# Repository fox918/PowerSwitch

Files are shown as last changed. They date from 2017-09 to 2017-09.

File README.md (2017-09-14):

# SmartPowerSwitch Project

## Idea
Having a simple and extensible way to switch 12V power with up to 10A with a microcontroller.
The intended use for the device is to remotely switch things at amateur radio repeater sites. 

## Concept
The idea is to use a Infineon SmartFET as powerswitch.
This reduces complexity because a lot of things are already taken care of and we can
further use the diagnostic outputs to measure the current.

Using an i2c GPIO expander and an i2c ADC allows for measuring supply voltage, current delivered to the output and temperature of the heatsink.

With a dip switch, we can change the address of both i2c devices simultaneously, therefore allowing 4 devices on the same i2c bus.

Look at [PowerSwitch Idea](./PowerSwitch_Idea.pdf) for a Block Schema.

## Current State
An initial approach of the [Schema](./Circuit_Schema_v2.pdf) and the PCB is done, after review a prototype shall be built.

### Current PCB
- [PCB Front](./PCB_front_v2.png) 
- [PCB_Back](./PCB_back_v2.png) 

### Current Issues
- Almost no protection circuits on the internal voltage source
- Current paths on the pcb not optimal (especially ground path)
- Choose a suitable connector for the i2c backplane (suggestion: rj12, JST SH or some 2.54mm connector)

## Further development
- Design a board to mount the two colored button
- Choose a ethernet enabled microcontroller and design a i2c shield for it 
(and a nice GUI)
- adapt the boards to mount into 1U rackunits with XLR 4-Pin connectors

## License
[MIT, 2017 Oliver Wisler](./LICENSE)

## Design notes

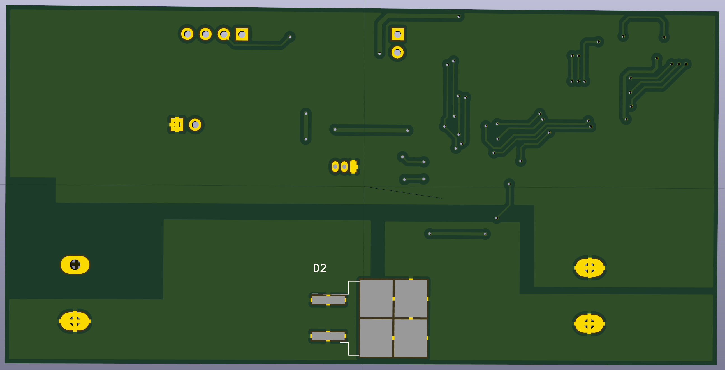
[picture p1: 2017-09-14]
PCB_back_v2.png

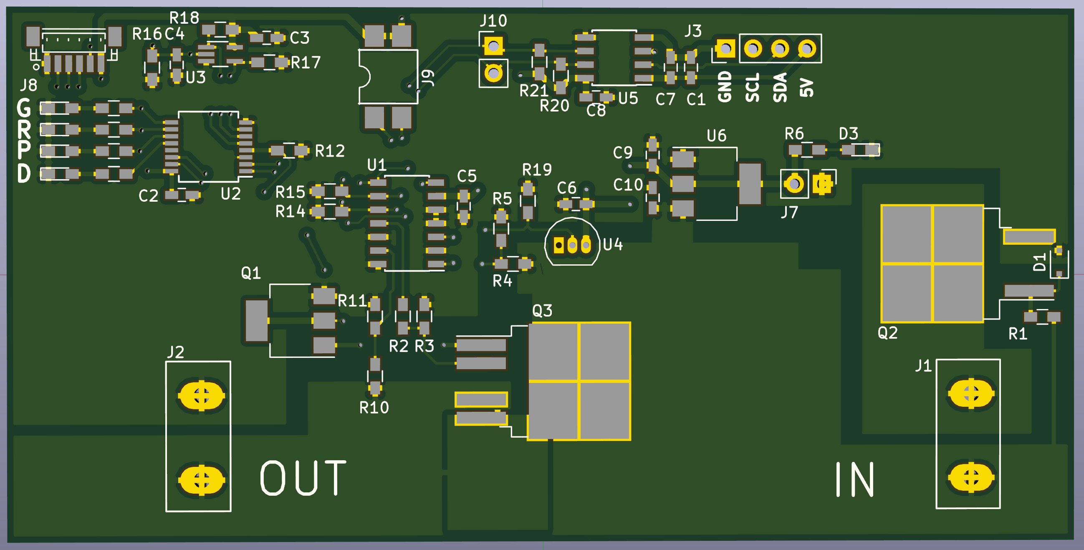
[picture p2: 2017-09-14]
PCB_front_v2.png

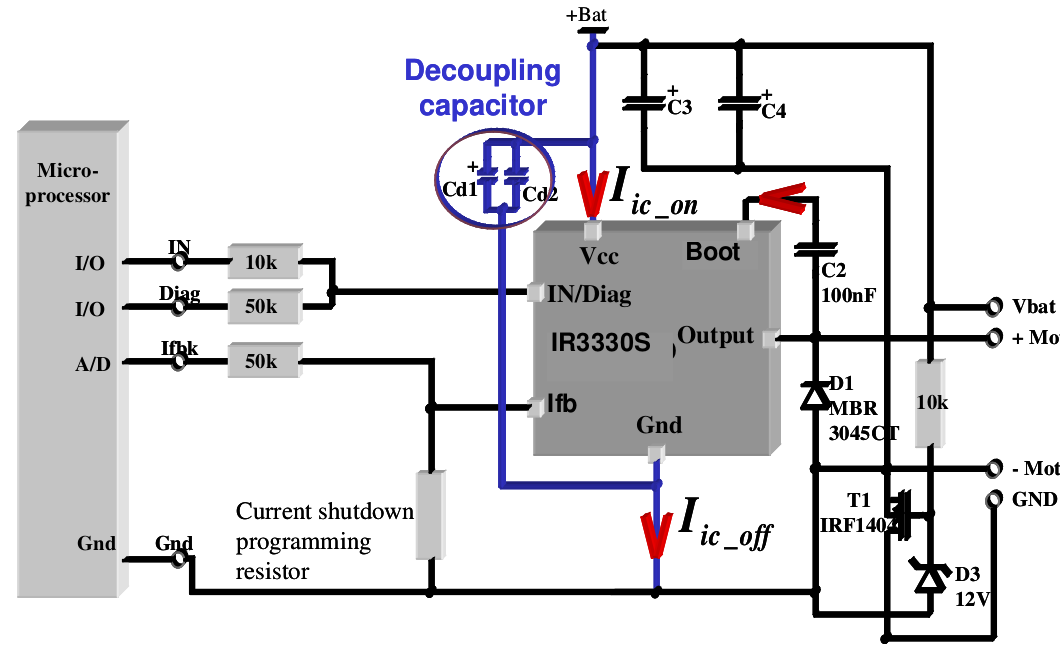
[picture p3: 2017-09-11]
Datasheets/Sample_Circuit_from_AUIR3330S.png

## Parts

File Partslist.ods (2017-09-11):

PowerSwitch Project Partslist
 |  | Green marked: | Parts chosen for the project
 |  | not marked | proposals, parts to keep an eye on
Connectors
Amount | Order Number | Part Nr | Description | Package
2 | 534-979 | 1327G6 | Powerpole Black
2 | 534-985 | 1327 | Powerpole Red
4 | 382-6108 | 1377G2 | Powerpole Right Angle PCB
 |  |  | RJ12 for i2c Connection to uC?
Button Circuit
Amount | Order Number | Part Nr | Description | Package
 |  | HB215SKG03CF-JB | NKK Taster R/G
 |  | FL12DRG5 | EOZ Taster R/G, too big?
1 | 198-069 | JB-15KNP2-KBS | NKK Taster Blau
1 | 816-8794 | 74LVC1G80GW | Flip Flop Taster
Power / Voltage
Amount | Order Number | Part Nr | Description | Package
 | 906-4432 | BTS50055-1TMC | POWERFET, Sense, 17 A | PG-TO220-7-4
 | 784-9338 | AUIR3330S | HIGH Side Switch | D2Pak 7 Leads
1 | 725-9209 | AUIPS7111S | PowerFET IPS7 | D2Pak 5 Leads
 | Accessories
1 | 698-8117 | FK 244 13 D PAK | Kühlkörper Dpak
1 | 698-8111 | FK 244 13 D2 PAK | Kühlkörper D2Pak
1 | 753-2816 | BSP318S | Logic NFET | SOT-223
Reverse Current and Protection
Amount | Order Number | Part Nr | Description | Package
1 | 651-8759 | IRF1404ZSPBF | Crowbar | D2Pak 2 Leads
1 | 770-4863 | DDZ12CSF-7 | Diode for Crowbar 12V | SOD-323F
1 | .249-167 | STPS40L45CG | Free Wheel Schottky | D2Pak 2 Leads
1 | 738-2829 | 0326015.MXP | Sicherung 15 A ()
2 | 703-2792 | 8040.0003 | Sicherungshalter
Sensing / Diagnostics
Amount | Order Number | Part Nr | Description | Package
1 | 703-7945 | MCP3428-E/SL | 4 Kanal I2C ADC from Microchip | SOIC-14
1 | 815-0683 | PCA9554DB | LED Driver / GPIO Switch | SSOP 16
1 | 811-5595 |  | LM35 Temp Sens | TO-92

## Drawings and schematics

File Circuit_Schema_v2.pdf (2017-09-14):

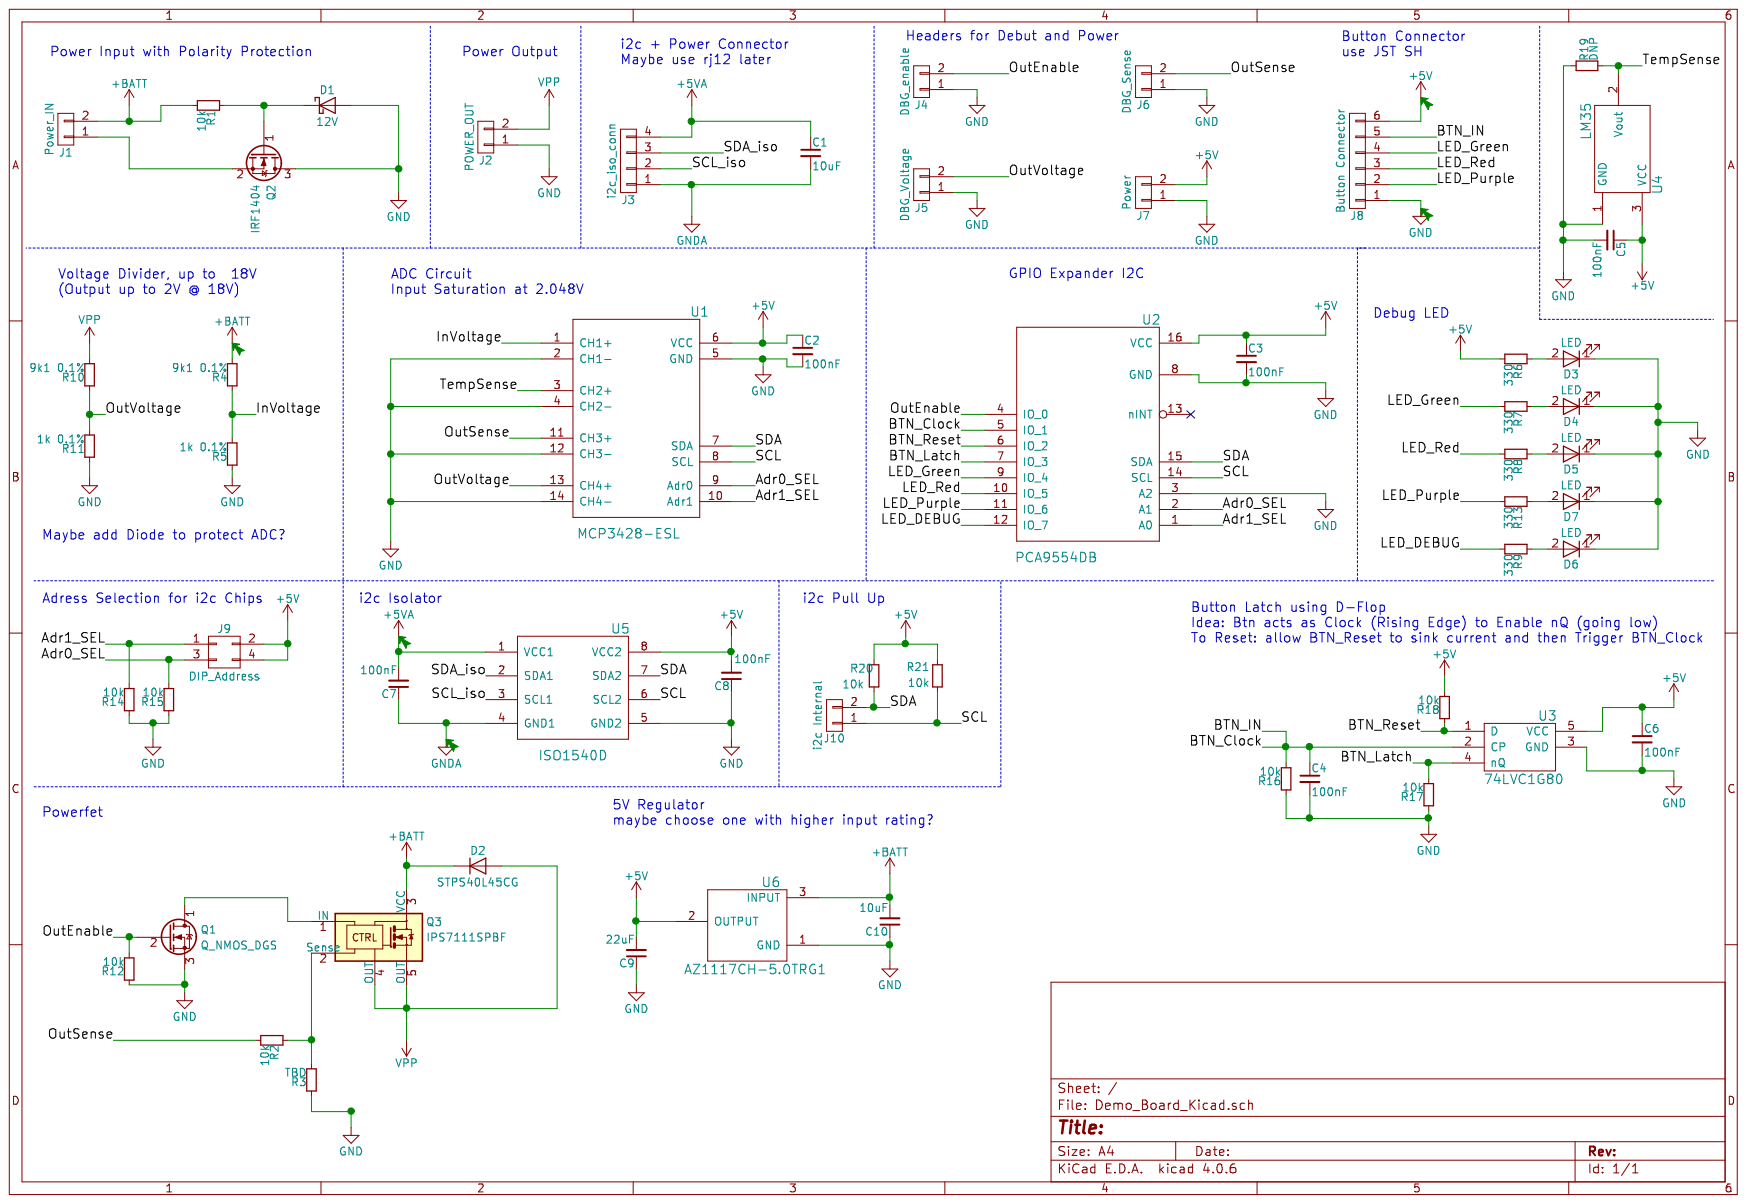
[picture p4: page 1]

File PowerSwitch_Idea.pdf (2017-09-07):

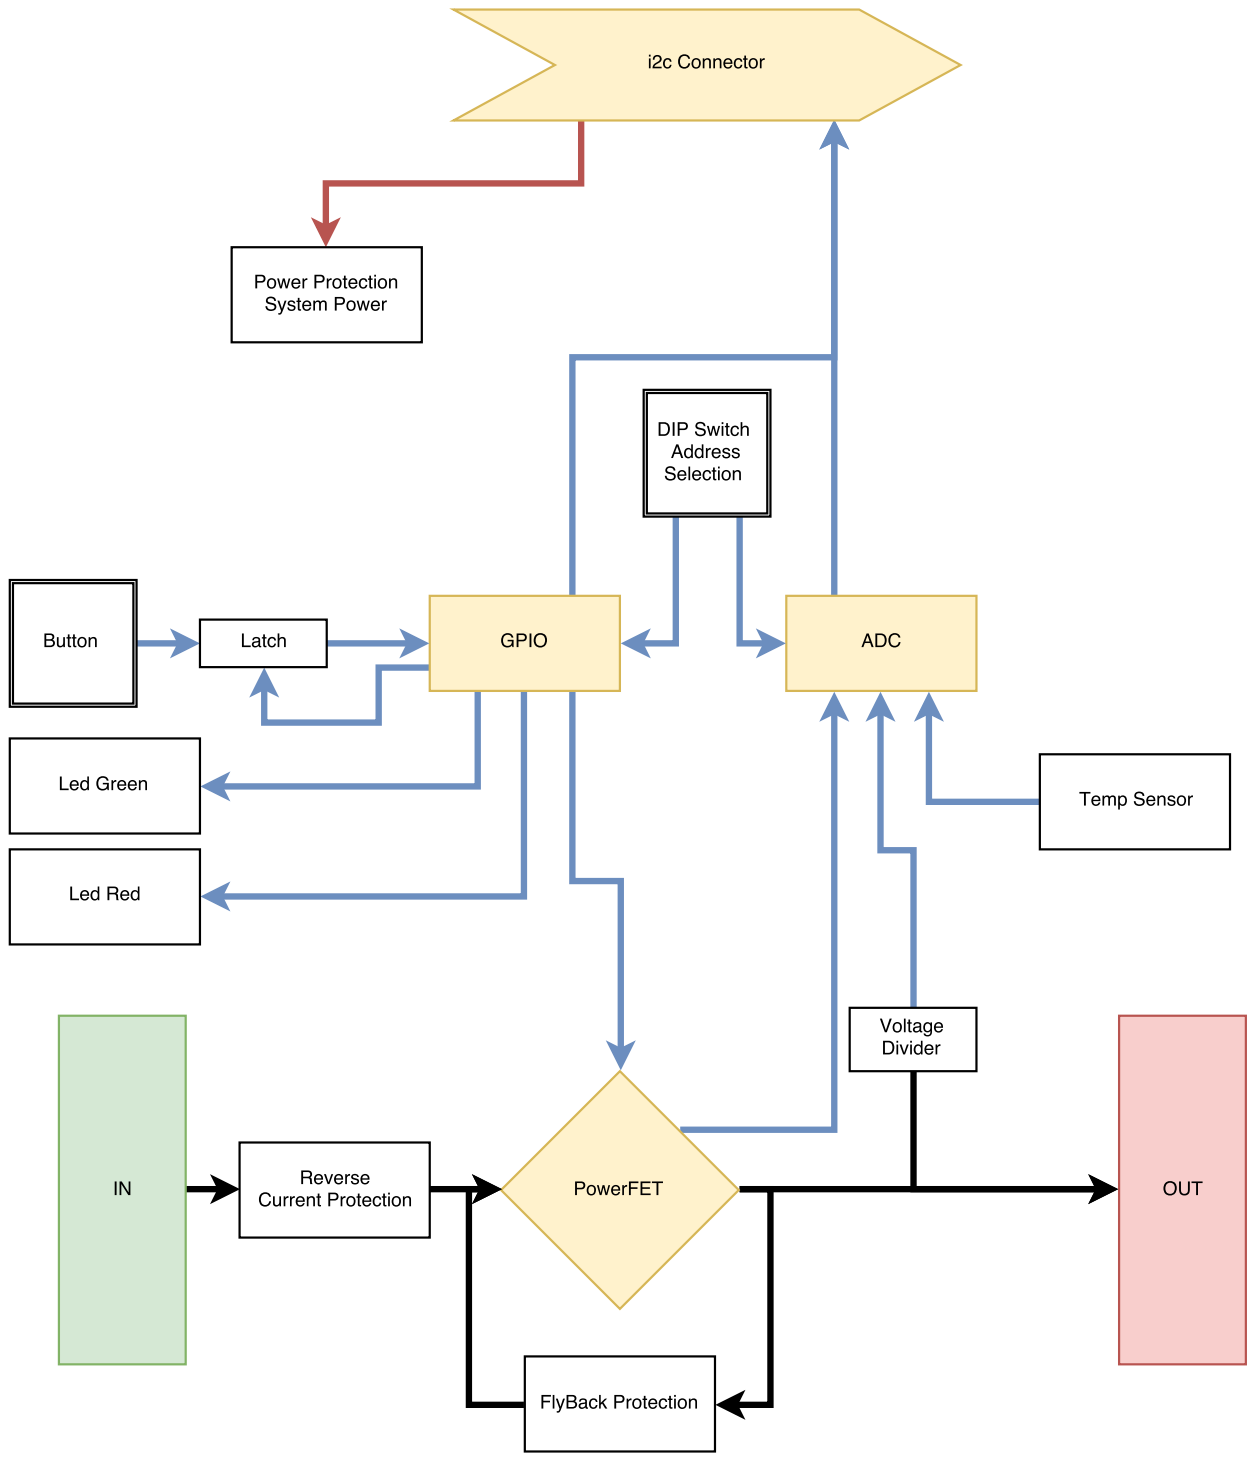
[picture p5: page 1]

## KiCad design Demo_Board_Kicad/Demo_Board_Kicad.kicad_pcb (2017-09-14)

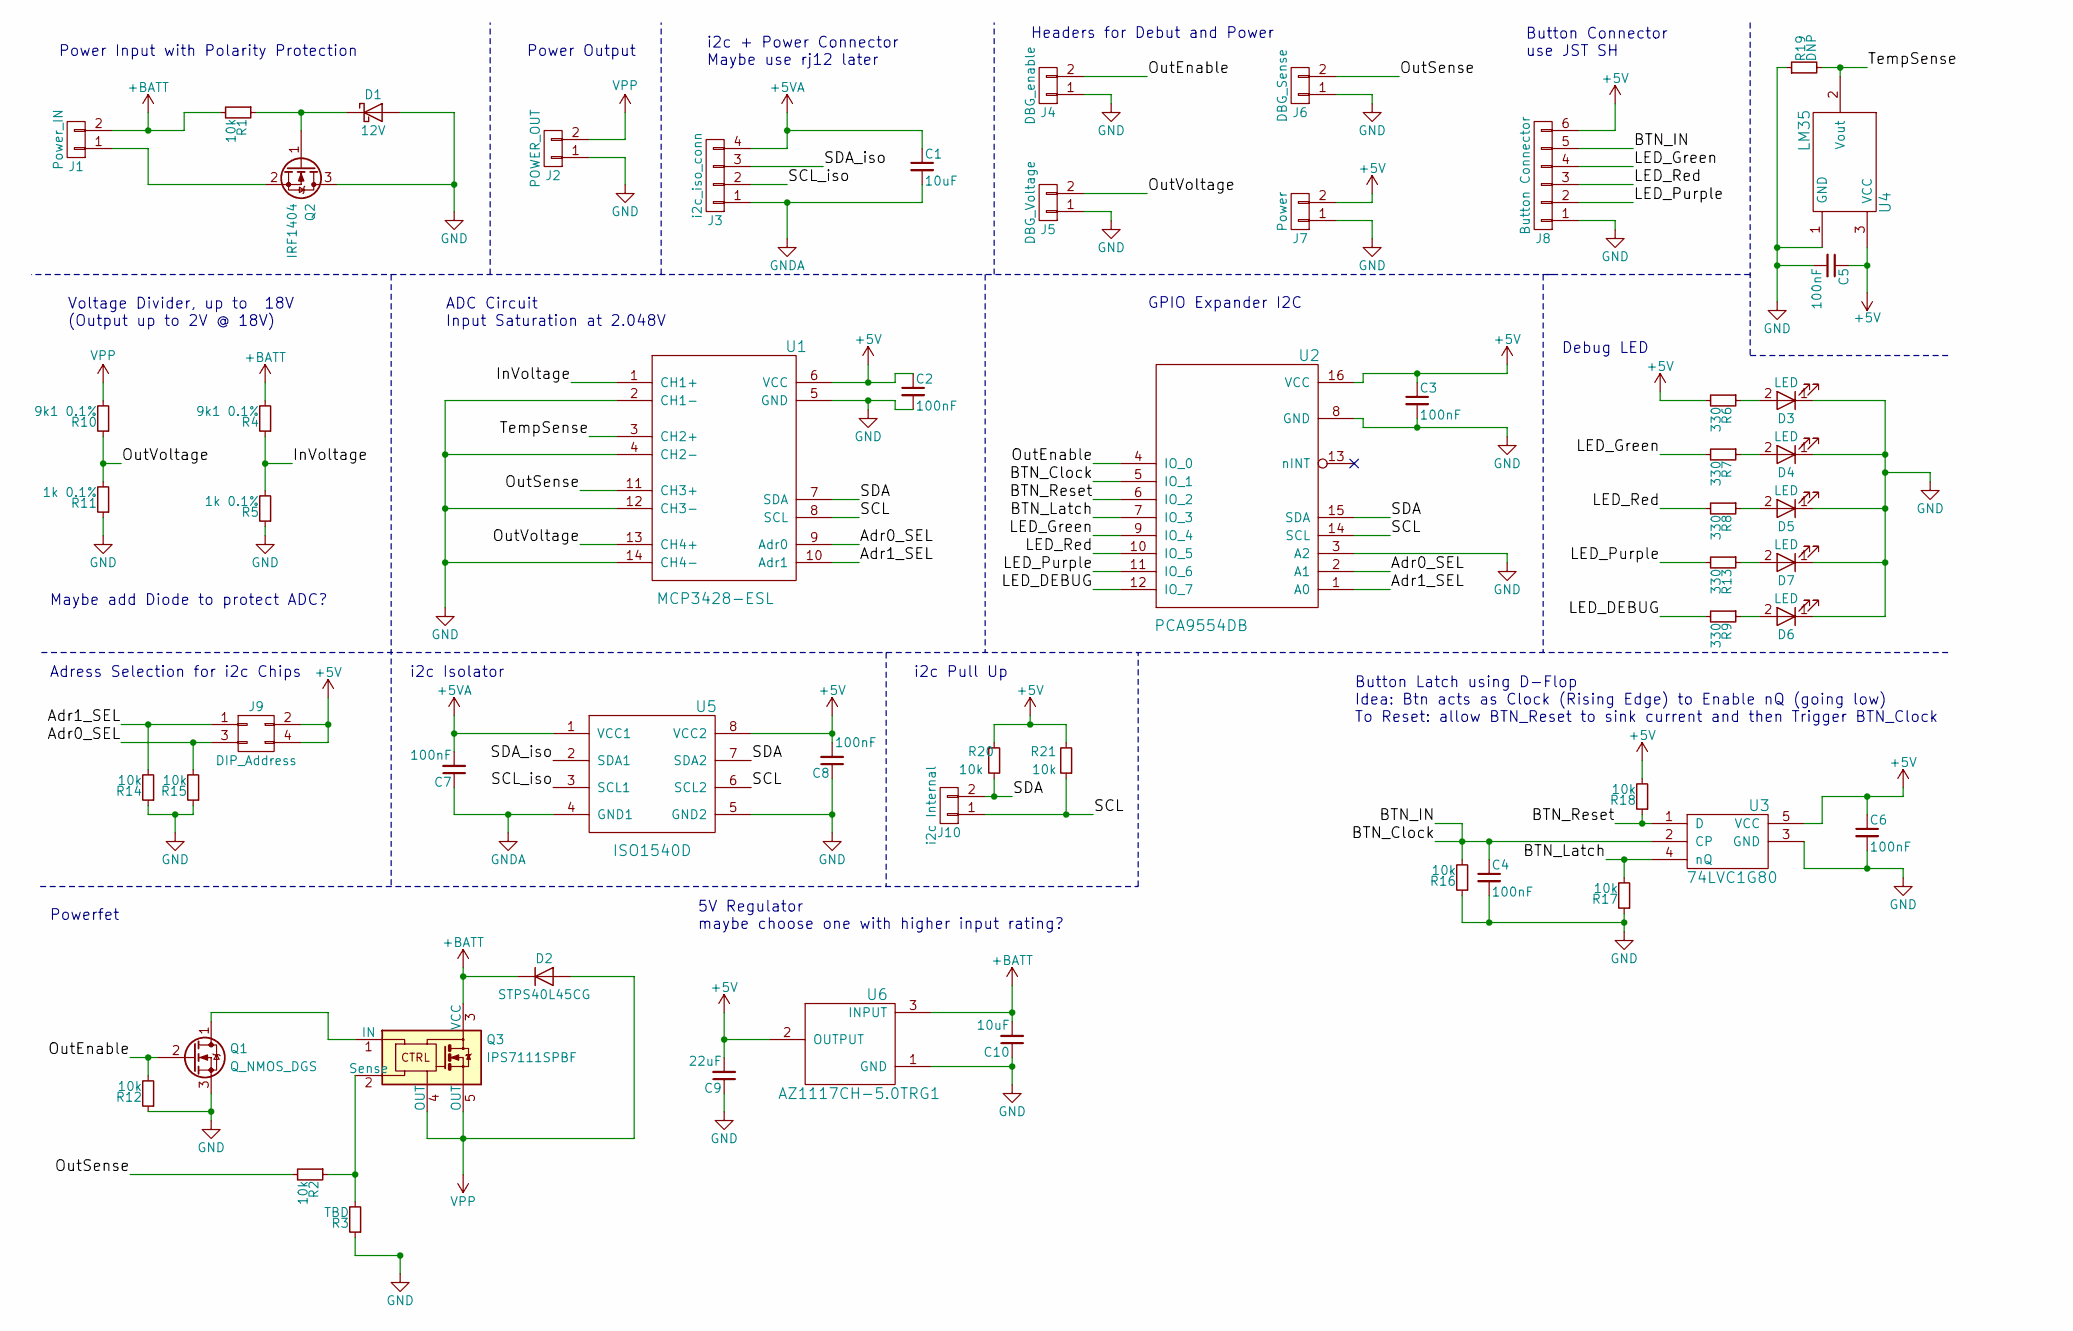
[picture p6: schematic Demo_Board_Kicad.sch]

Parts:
C1, C10: 10uF; C_0603_HandSoldering
C2, C3, C4, C5, C6, C7, C8: 100nF; C_0603_HandSoldering
C9: 22uF; C_0603_HandSoldering
D1: 12V; D_SOD-323F
D2: STPS40L45CG; TO-263-2
D3, D4, D5, D6, D7: LED; LED_0603_HandSoldering
J1: Power_IN; PowerPole2P
J2: POWER_OUT; PowerPole2P
J3: i2c_iso_conn; Pin_Header_Straight_1x04_Pitch2.54mm
J4: DBG_enable; Pin_Header_Straight_1x02_Pitch2.54mm
J5: DBG_Voltage; Pin_Header_Straight_1x02_Pitch2.54mm
J6: DBG_Sense; Pin_Header_Straight_1x02_Pitch2.54mm
J7: Power; Pin_Header_Straight_1x02_Pitch2.54mm
J8: Button Connector; JST_SH_BM06B-SRSS-TB_06x1.00mm_Straight
J9: DIP_Address; DIP-6_W7.62mm_SMD
J10: i2c Internal; Pin_Header_Straight_1x02_Pitch2.54mm
Q1: Q_NMOS_DGS; SOT-223-3Lead_TabPin2
Q2: IRF1404; TO-263-2
Q3: IPS7111SPBF; TO-263-4
R1, R2, R12, R14, R15, R16, R17, R18, R20, R21: 10k; R_0603_HandSoldering
R3: TBD; R_0603_HandSoldering
R4, R10: 9k1 0.1%; R_0603_HandSoldering
R5, R11: 1k 0.1%; R_0603_HandSoldering
R6, R7, R8, R9, R13: 330; R_0603_HandSoldering
R19: DNP; R_0603_HandSoldering
U1: MCP3428-ESL; SOIC-14_3.9x8.7mm_Pitch1.27mm
U2: PCA9554DB; SSOP-16_5.3x6.2mm_Pitch0.65mm
U3: 74LVC1G80; SOT-353_SC-70-5_Handsoldering
U4: LM35; TO-92_Inline_Narrow_Oval
U5: ISO1540D; SOIC-8_3.9x4.9mm_Pitch1.27mm
U6: AZ1117CH-5.0TRG1; SOT-223-3Lead_TabPin2

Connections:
+5V: C2.1, C3.1, C5.1, C6.1, C8.2, C9.2, J7.2, J8.6, J9.2, J9.4, R6.2, R18.2, R20.1, R21.2, U1.6 (VCC), U2.16 (VCC), U3.5 (VCC), U4.3 (VCC), U5.8 (VCC2), U6.2 (OUTPUT)
+5VA: C1.1, C7.2, J3.4, U5.1 (VCC1)
+BATT: C10.2, D2.1 (K), J1.2, Q3.3 (VCC), R1.2, R4.2, U6.3 (INPUT)
/Adr0_SEL: J9.3, R15.2, U1.9 (Adr0), U2.2 (A1)
/Adr1_SEL: J9.1, R14.2, U1.10 (Adr1), U2.1 (A0)
/BTN_Clock: C4.1, J8.5, R16.2, U2.5 (IO_1), U3.2 (CP)
/BTN_Latch: R17.2, U2.7 (IO_3), U3.4 (nQ)
/BTN_Reset: R18.1, U2.6 (IO_2), U3.1 (D)
/InVoltage: R4.1, R5.2, U1.1 (CH1+)
/LED_DEBUG: R9.2, U2.12 (IO_7)
/LED_Green: J8.4, R7.2, U2.9 (IO_4)
/LED_Purple: J8.2, R13.2, U2.11 (IO_6)
/LED_Red: J8.3, R8.2, U2.10 (IO_5)
/OutEnable: J4.2, Q1.2 (G), R12.2, U2.4 (IO_0)
/OutSense: J6.2, R2.2, U1.11 (CH3+)
/OutVoltage: J5.2, R10.1, R11.2, U1.13 (CH4+)
/SCL: J10.1, R21.1, U1.8 (SCL), U2.14 (SCL), U5.6 (SCL2)
/SCL_iso: J3.2, U5.3 (SCL1)
/SDA: J10.2, R20.2, U1.7 (SDA), U2.15 (SDA), U5.7 (SDA2)
/SDA_iso: J3.3, U5.2 (SDA1)
/TempSense: R19.2, U1.3 (CH2+), U4.2 (Vout)
GND: C2.2, C3.2, C4.2, C5.2, C6.2, C8.1, C9.1, C10.1, D1.2 (A), D3.1 (K), D4.1 (K), D5.1 (K), D6.1 (K), D7.1 (K), J2.1, J4.1, J5.1, J6.1, J7.1, J8.1, Q1.3 (S), Q2.3 (D), R3.1, R5.1, R11.1, R12.1, R14.1, R15.1, R16.1, R17.1, R19.1, U1.2 (CH1-), U1.4 (CH2-), U1.5 (GND), U1.12 (CH3-), U1.14 (CH4-), U2.3 (A2), U2.8 (GND), U3.3 (GND), U4.1 (GND), U5.5 (GND2), U6.1 (GND)
GNDA: C1.2, C7.1, J3.1, U5.4 (GND1)
unnamed: D1.1 (K), Q2.1 (G), R1.1
unnamed: D3.2 (A), R6.1
unnamed: D4.2 (A), R7.1
unnamed: D5.2 (A), R8.1
unnamed: D6.2 (A), R9.1
unnamed: D7.2 (A), R13.1
unnamed: J1.1, Q2.2 (S)
unnamed: Q1.1 (D), Q3.1 (IN)
unnamed: Q3.2 (Sense), R2.1, R3.2
VPP: D2.2 (A), J2.2, Q3.4 (OUT), Q3.5 (OUT), R10.2

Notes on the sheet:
Power Input with Polarity Protection
Voltage Divider, up to 18V (Output up to 2V @ 18V)
Power Output
i2c + Power Connector Maybe use rj12 later
Button Connector use JST SH
Debug LED
Headers for Debut and Power
Maybe add Diode to protect ADC?
ADC Circuit Input Saturation at 2.048V
GPIO Expander I2C
Button Latch using D-Flop Idea: Btn acts as Clock (Rising Edge) to Enable nQ (going low) To Reset: allow BTN_Reset to sink current and then Trigger BTN_Clock
Adress Selection for i2c Chips
i2c Isolator
i2c Pull Up
Powerfet
5V Regulator maybe choose one with higher input rating?

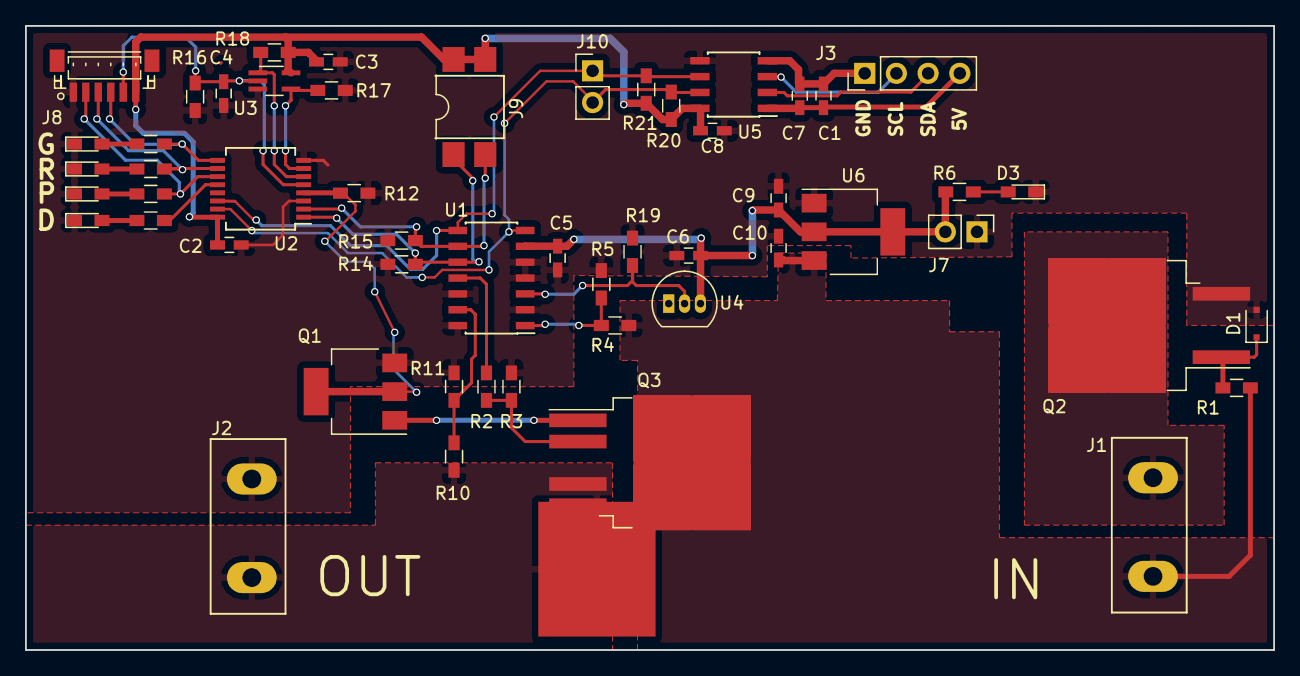
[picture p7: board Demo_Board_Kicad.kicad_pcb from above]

Board: 2 copper layers, 100.0 x 50.0 mm, 54 parts (1 on the bottom side), 33 nets.

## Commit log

2017-09-07 searched parts
    [Partslist.ods]
2017-09-11 cleanup files
    [Demo_Board_Kicad.kicad_pcb, Demo_Board_Kicad.sch, Partslist.ods]
2017-09-14 reworked pcb and added new files
    [Demo_Board_Kicad.kicad_pcb, Demo_Board_Kicad.sch]
